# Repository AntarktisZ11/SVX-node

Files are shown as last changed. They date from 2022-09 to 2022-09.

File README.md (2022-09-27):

# SA6MBO SVX-node
A basic UHF or VHF node designed around a SA868 fitted as a HAT on top of an [Orange Pi Zero LTS](http://www.orangepi.org/html/hardWare/computerAndMicrocontrollers/details/Orange-Pi-Zero-LTS.html "Orange Pi Zero LTS"). The repeater software is the [SVXLink project](https://github.com/sm0svx/svxlink "SVXLink project") with configuration inspired by the [ROLink community](http://www.439100.ro/ "ROLink community"). The origin of this project is courtesy of [SM6TZL](https://svxportal.sm2ampr.net/station_info.php?callsign=SM6TZL&no_header=true "SM6TZL")'s small mobile unit. A massive praise goes to VoltLogs [VoltNode](https://github.com/voltlog/VoltNode "VoltNode") for comprising the work into a manageable PCB along with short but good documentation.

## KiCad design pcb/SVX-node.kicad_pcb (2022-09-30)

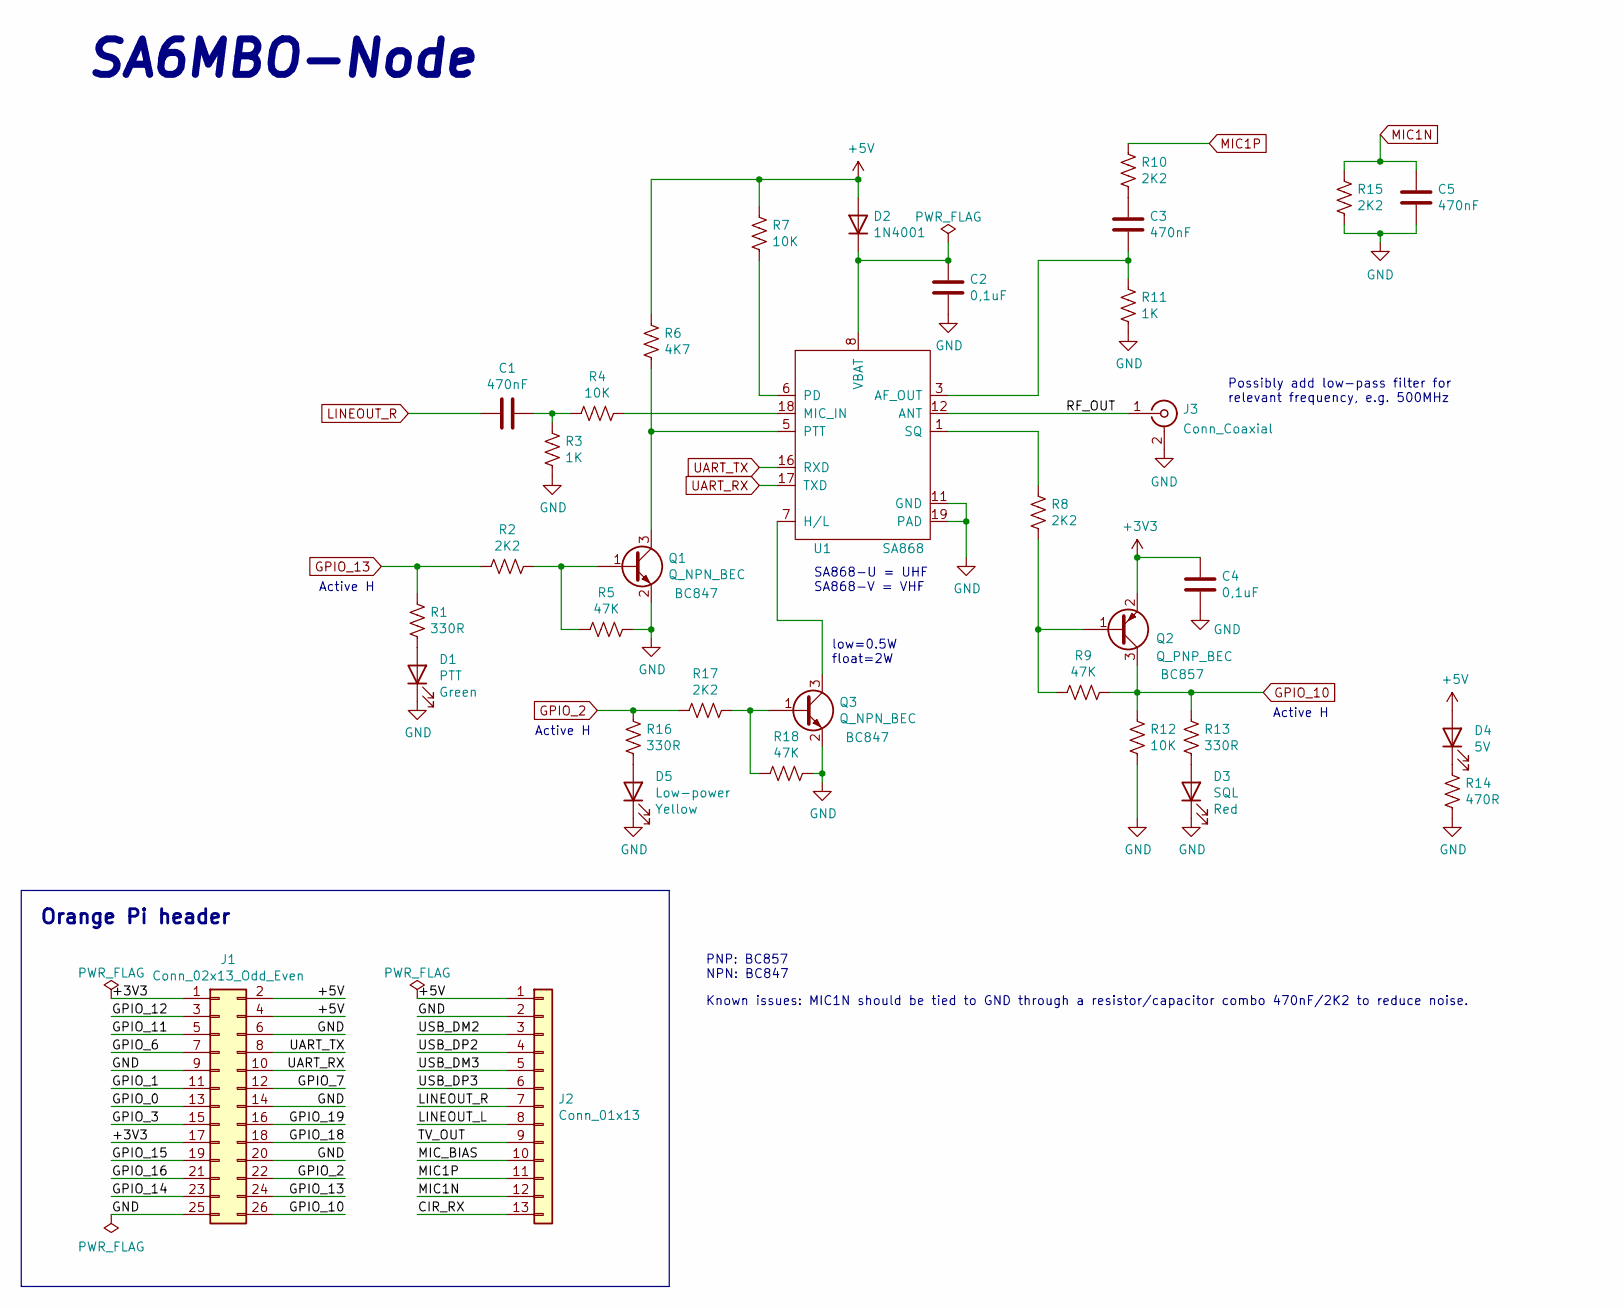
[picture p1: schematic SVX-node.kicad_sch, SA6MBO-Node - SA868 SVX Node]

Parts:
C1, C3, C5: 470nF; C_0603_1608Metric
C2, C4: 0,1uF; C_0603_1608Metric
D1: PTT; LED_0603_1608Metric
D2: 1N4001; D_DO-41_SOD81_P5.08mm_Vertical_KathodeUp
D3: SQL; LED_0603_1608Metric
D4: 5V; LED_0603_1608Metric
D5: Low-power; LED_0603_1608Metric
J1: Conn_02x13_Odd_Even; PinSocket_2x13_P2.54mm_Vertical
J2: Conn_01x13; PinSocket_1x13_P2.54mm_Vertical
J3: Conn_Coaxial; SMA_Amphenol_132291-12_Vertical
Q1, Q3: Q_NPN_BEC; TO-92_Inline_Wide
Q2: Q_PNP_BEC; TO-92_Inline_Wide
R1, R13, R16: 330R; R_0603_1608Metric
R2, R8, R10, R15, R17: 2K2; R_0603_1608Metric
R3, R11: 1K; R_0603_1608Metric
R4, R7, R12: 10K; R_0603_1608Metric
R5, R18: 47K; R_0603_1608Metric
R6: 4K7; R_0603_1608Metric
R9: 47K; R_Axial_DIN0204_L3.6mm_D1.6mm_P5.08mm_Horizontal
R14: 470R; R_0603_1608Metric
U1: SA868

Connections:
+3V3: C4.1, J1.1, J1.17, Q2.2 (E)
+5V: D2.2 (A), D4.2 (A), J1.2, J1.4, J2.1, R6.1, R7.1
/CIR_RX: J2.13
/GPIO_0: J1.13
/GPIO_1: J1.11
/GPIO_3: J1.15
/GPIO_6: J1.7
/GPIO_7: J1.12
/GPIO_11: J1.5
/GPIO_12: J1.3
/GPIO_14: J1.23
/GPIO_15: J1.19
/GPIO_16: J1.21
/GPIO_18: J1.18
/GPIO_19: J1.16
/LINEOUT_L: J2.8
/MIC_BIAS: J2.10
/RF_OUT: J3.1 (In), U1.12 (ANT)
/TV_OUT: J2.9
/USB_DM2: J2.3
/USB_DM3: J2.5
/USB_DP2: J2.4
/USB_DP3: J2.6
GND: C2.2, C4.2, C5.2, D1.1 (K), D3.1 (K), D5.1 (K), J1.6, J1.9, J1.14, J1.20, J1.25, J2.2, J3.2 (Ext), Q1.2 (E), Q3.2 (E), R3.2, R5.1, R11.2, R12.2, R14.2, R15.2, R18.1, U1.9, U1.10, U1.11 (GND), U1.19 (PAD)
GPIO_2: J1.22, R16.1, R17.2
GPIO_10: J1.26, Q2.3 (C), R9.2, R12.1, R13.1
GPIO_13: J1.24, R1.1, R2.2
LINEOUT_R: C1.2, J2.7
MIC1N: C5.1, J2.12, R15.1
MIC1P: J2.11, R10.1
unnamed: C1.1, R3.1, R4.2
unnamed: C2.1, D2.1 (K), U1.8 (VBAT)
unnamed: C3.1, R10.2
unnamed: C3.2, R11.1, U1.3 (AF_OUT)
unnamed: D1.2 (A), R1.2
unnamed: D3.2 (A), R13.2
unnamed: D4.1 (K), R14.1
unnamed: D5.2 (A), R16.2
unnamed: Q1.1 (B), R2.1, R5.2
unnamed: Q1.3 (C), R6.2, U1.5 (PTT)
unnamed: Q2.1 (B), R8.2, R9.1
unnamed: Q3.1 (B), R17.1, R18.2
unnamed: Q3.3 (C), U1.7 (H/L)
unnamed: R4.1, U1.18 (MIC_IN)
unnamed: R7.2, U1.6 (PD)
unnamed: R8.1, U1.1 (SQ)
UART_RX: J1.10, U1.17 (TXD)
UART_TX: J1.8, U1.16 (RXD)

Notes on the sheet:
PNP: BC857 NPN: BC847
Orange Pi header
Active H
Possibly add low-pass filter for relevant frequency, e.g. 500MHz
Known issues: MIC1N should be tied to GND through a resistor/capacitor combo 470nF/2K2 to reduce noise.
SA868-U = UHF SA868-V = VHF
low=0.5W float=2W
SA6MBO-Node

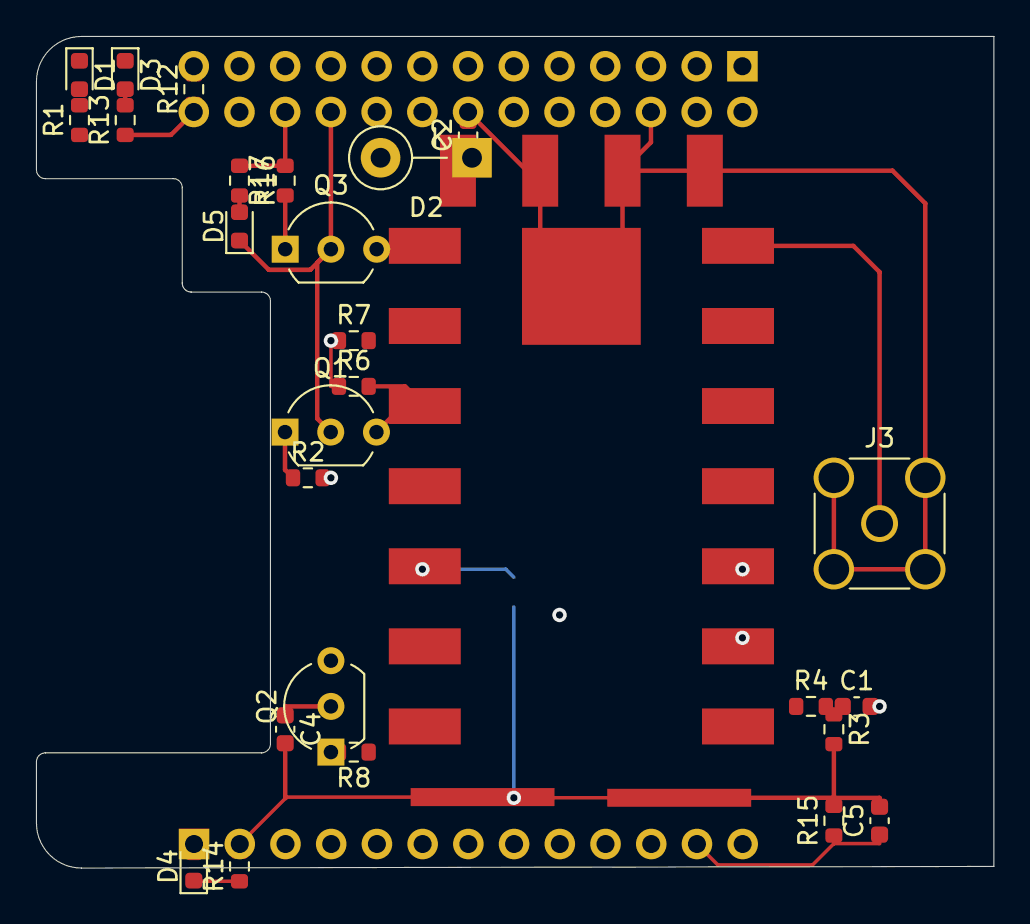
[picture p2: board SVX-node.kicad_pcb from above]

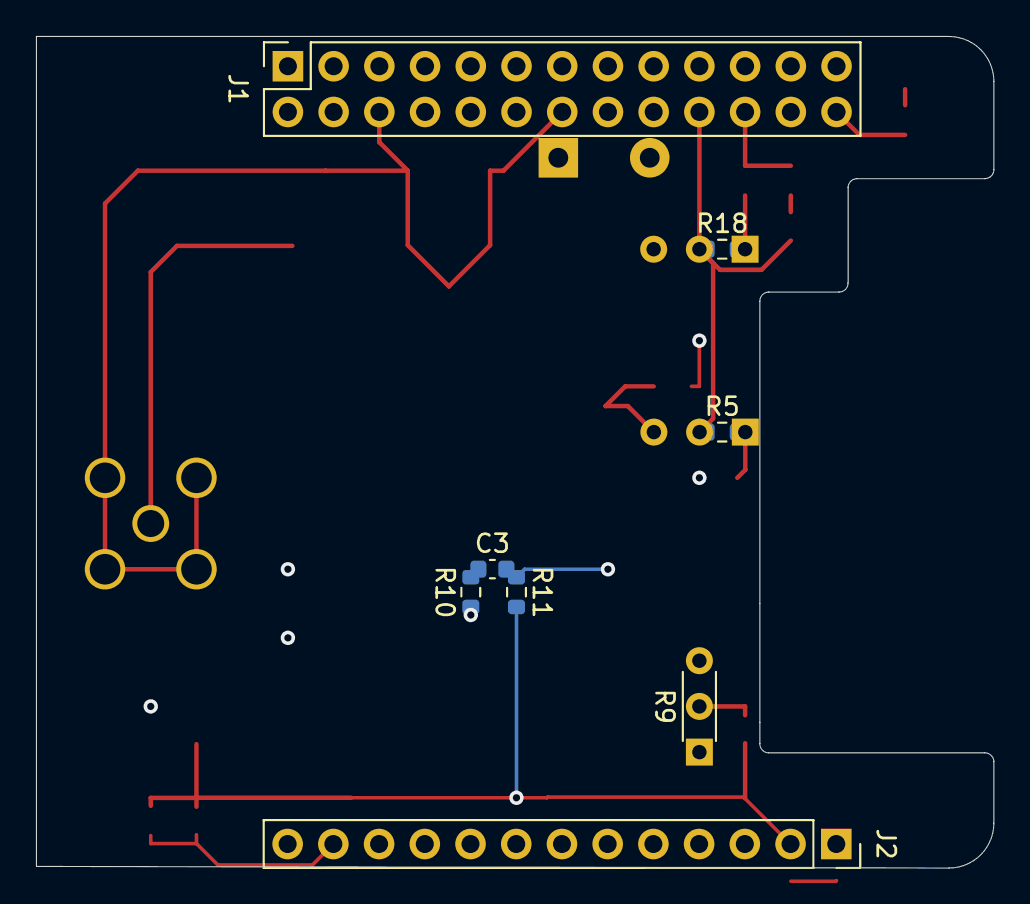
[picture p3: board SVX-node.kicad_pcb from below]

Board: 4 copper layers, 53.2 x 46.2 mm, 35 parts (8 on the bottom side), 28 nets.

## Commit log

2022-09-27 fix: replace broken SA818 component with new SA868
    [SVX-node.kicad_sch]
2022-09-30 feat: Finalize pcb layout for protoboard assembly
    [SVX-node.kicad_pcb, SVX-node.kicad_sch]
